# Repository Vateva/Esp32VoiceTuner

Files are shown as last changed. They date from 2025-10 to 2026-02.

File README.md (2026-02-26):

# esp32-s3-voice-tuner
Real-time voice/instrument tuner using ESP32-S3 with dual-core FreeRTOS, YIN pitch detection, and round GC9A01 display.

Main objective is to learn multithreading with true parallel processing across multiple cores and gain deeper experience with embedded systems development.

## Table of Contents
- [Hardware Components](#hardware-components)
- [Pinout Configuration](#pinout-configuration)
- [Wiring and Assembly](#wiring-and-assembly)
- [Key Features](#key-features)
- [Technical Specifications](#technical-specifications)
- [Known Limitations](#known-limitations)
- [Build Environment](#build-environment)
- [Videos](#videos)

## Hardware Components
- ESP32-S3 Super Mini (or ESP32-S3 Zero)
- GC9A01 Round Display (240x240, 1.28")
- INMP441 MEMS Microphone
- TP4056 Charging Module
- 3.7V 3000mAh Li-Ion Battery
- 2x Momentary Push Buttons
- Power Switch

## Pinout Configuration

### GC9A01 Display (SPI)
```cpp
TFT_SCK  = GPIO 1   // SPI clock
TFT_MOSI = GPIO 2   // SPI data out
TFT_CS   = GPIO 5   // chip select
TFT_DC   = GPIO 4   // data/command
TFT_RST  = GPIO 3   // reset
TFT_BLK  = GPIO 6   // backlight (PWM controlled)
```

### INMP441 Microphone (I2S)
```cpp
I2S_SCK = GPIO 13   // bit clock
I2S_WS  = GPIO 12   // word select (LRCK)
I2S_SD  = GPIO 11   // serial data
```

### Control Buttons
```cpp
BUTTON_DOWN   = GPIO 10  // menu navigation (with internal pullup)
BUTTON_SELECT = GPIO 9   // menu entry/parameter cycling (with internal pullup)
```

Buttons are active low (pressed = LOW, released = HIGH)

## Wiring and Assembly

### Breadboard
tunerBreadBoard

### Soldered guts
tunerSoloderedGuts

### Casing
casing

### In casing
inCasing

### Finished
tunerFinished1

**Power:**
- TP4056 handles battery charging via USB
- Power switch controls main power
- Battery provides portable operation

## Key Features

### True Dual-Core Processing
Leverages both ESP32-S3 cores for parallel processing:
- **Core 0 (Audio Task):** continuous I2S audio capture at 48kHz, dB level monitoring, power state management
- **Core 1 (Processing Task):** YIN pitch detection, display rendering, menu system, button handling
- FreeRTOS queues and mutexes ensure thread-safe communication
- Independent task priorities prevent blocking

### YIN Pitch Detection Algorithm
Two-pass implementation with harmonic validation:
- **Coarse Pass:** fast period estimation using 512 samples, quality gating at 0.5 threshold
- **Refined Pass:** focused search window (±40% configurable) around coarse estimate, parabolic interpolation for sub-sample precision
- **Harmonic Scoring:** validates fundamental by checking 2nd, 3rd, and 4th harmonics with weighted correlation
- **Multi-Candidate Ranking:** evaluates up to 8 period candidates using composite scoring (YIN quality 40%, harmonic content 50%, frequency bias 10%)

### Audio Preprocessing
Cascaded 2nd-order Butterworth IIR filters:
- **Highpass Filter:** removes DC offset and low frequency noise (60-120Hz configurable)
- **Lowpass Filter:** removes high frequency noise above vocal harmonics (4000-8000Hz configurable)
- **Audio Gain:** input amplification (1.0x to 10.0x configurable)

### Confidence-Based Smoothing
Multi-factor confidence calculation for adaptive filtering:
- **YIN Quality (35%):** exponential decay based on YIN difference function value
- **Harmonic Content (25%):** strength of detected harmonics in signal
- **Signal Strength (25%):** sigmoid-mapped RMS level
- **Frequency Stability (15%):** variance of recent 5 measurements
- Dynamic EMA alpha (0.25-0.85) scales smoothing based on overall confidence
- Automatic note change detection with immediate acquisition (6% frequency change threshold)

### Power Management
dB-based audio detection with dynamic CPU frequency scaling:
- **Detecting Mode:** 80MHz CPU, skips YIN analysis, monitors dB level only, displays animated sleep screen
- **Analyzing Mode:** 240MHz CPU, full pitch detection pipeline, normal tuner display
- Configurable activation threshold (-10 to -25dB), deactivation threshold (-20 to -40dB), silence timeout (2-10 seconds)
- Retriggerable timer prevents premature sleep during pauses

### Menu System
Comprehensive parameter configuration with flash persistence:
- **Tuning Parameters:** flat/sharp threshold (10-25 cents), smoothing level (1-5), scale selection (10 scales), root note (12 notes)
- **Audio Prefiltering:** highpass/lowpass cutoffs, audio gain
- **Display Settings:** brightness (PWM controlled 10-100%), cents display toggle, note naming (English/Solfège)
- **System Settings:** silence timeout, YIN search window, menu timeout, factory reset
- Two-button navigation (DOWN=navigate, SELECT=enter/cycle)
- Auto-save on exit with validation

### Musical Scales
Supports 10 different scales with configurable root note:
- Chromatic (all 12 notes)
- Major, Natural Minor, Harmonic Minor, Melodic Minor
- Major Pentatonic, Minor Pentatonic
- Blues, Dorian, Mixolydian
- Automatically snaps detected frequency to nearest scale note
- Calculates cents offset from perfect pitch within selected scale

## Technical Specifications

### Performance
- **Sample Rate:** 48kHz mono
- **Buffer Size:** 2048 samples (~43ms audio window)
- **Capture Interval:** 64ms (15.6 fps processing rate)
- **End-to-End Latency:** ~35ms (capture → analysis → display)
- **Frequency Range:** 40-1000Hz (code supports), 90-1000Hz (stable/verified)

## Known Limitations
- **Frequency Range:** while code theoretically supports 40-1000Hz, stable/reliable detection verified in 90-1000Hz range
- **Display Hardware:** code specifically written for GC9A01 240x240 round display, other displays require code modifications
- **Microphone Positioning:** optimal performance at ~15cm distance (varies with volume/gain settings)

## Build Environment
**PlatformIO Configuration:**
- Board: `esp32-s3-devkitc-1`
- Framework: Arduino-ESP32
- Library Dependencies: `lovyan03/LovyanGFX@^1.1.12`

Upload with default PlatformIO settings - no special configuration required.

## Videos

### Test video

https://github.com/user-attachments/assets/ada7eb09-d798-44a8-a253-f5996cc67c34

### Menu navigation and sleep

https://github.com/user-attachments/assets/7b2660a6-9329-4d96-aefc-cad8921d8ced

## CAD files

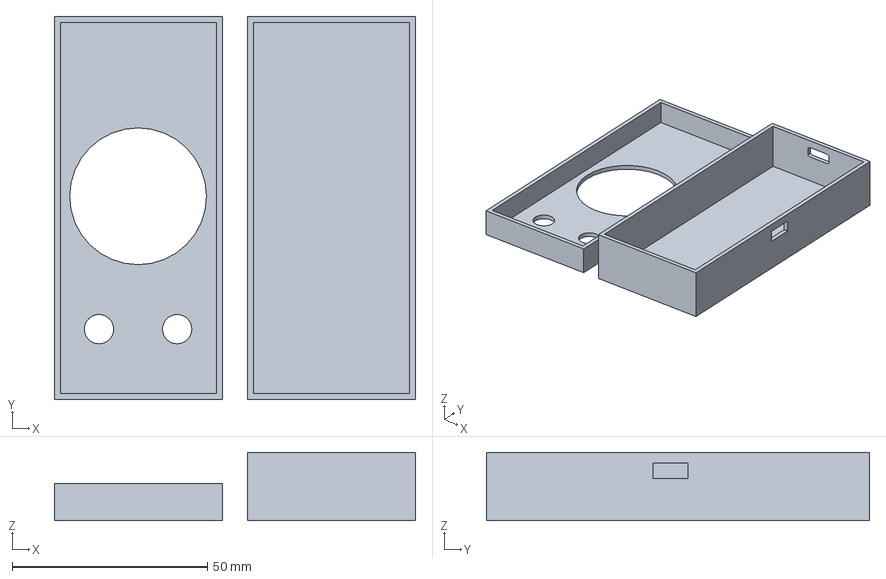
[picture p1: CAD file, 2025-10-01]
casingFiles3DPrint/tunerWithMicHoles.3mf
92.4 x 98.0 x 17.5 mm

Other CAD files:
casingFiles3DPrint/tunerNoMicHoles.stl
casingFiles3DPrint/tuner.blend

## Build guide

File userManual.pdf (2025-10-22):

# Voice Tuner

### User Manual

## Contents

Quick Start | 3
Button Controls | 4
Power Saving | 5
Menu Navigation | 6
Tuning Parameters | 7
Scale Types | 10
Audio Settings | 11
Display Settings | 13
System Settings | 15
Troubleshooting | 17
Tips & Best Results | 19

## Quick Start

Your voice tuner displays a circular interface showing pitch accuracy in real-time.
Circle Colors

Green: Perfect pitch (within threshold) Yellow/Orange: Close but slightly off Red: Significantly sharp or flat
What You See

The device shows the note name (like "C4", "A3") and cents deviation from perfect pitch.

The dynamic circle grows or shrinks to show how far you are from the target note.

Cents: A cent is 1/100th of a semitone. 0 cents = perfect pitch.

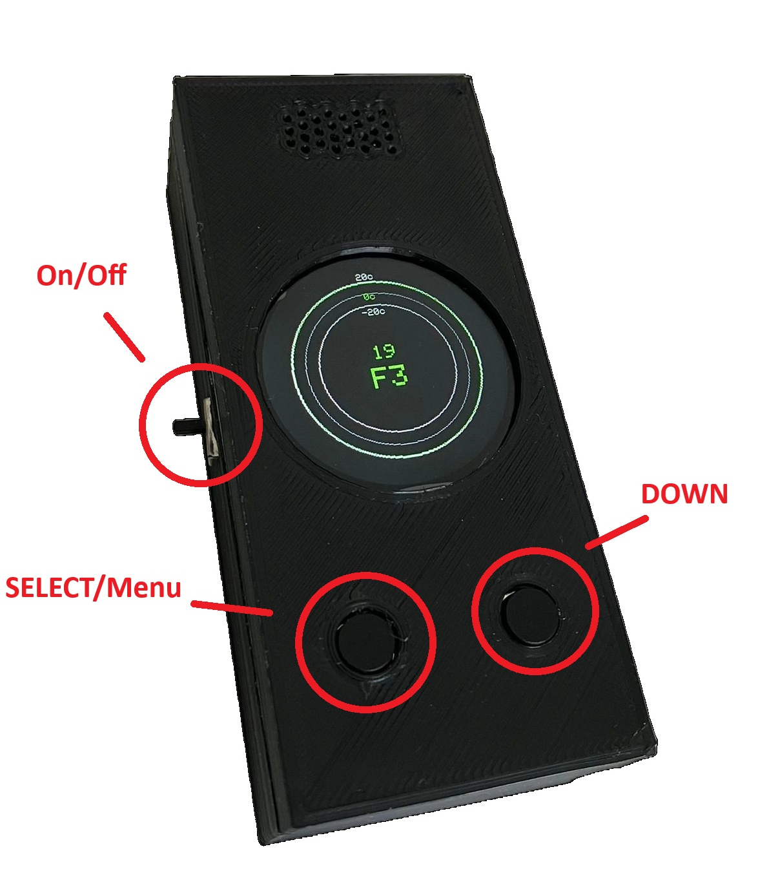
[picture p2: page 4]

## Button Controls

DOWN Button

Navigate down through menu items. The selection loops around to the top when you reach the bottom.
SELECT Button

Multi-function button:

Open the menu from tuner screen Enter submenu
Cycle through parameter values

Quick Access: Press SELECT once from the tuner screen to open the menu.

Navigation Flow

### 1. Press SELECT to open menu 2. Press DOWN to navigate 3. Press SELECT to enter/change 4. Select "Exit" to apply changes

## Power Saving Mode

The tuner automatically enters sleep mode when no sound is detected for several seconds.
Sleep Display

You'll see animated "zzz" characters floating upward with the message "Asleep but listening..."
Auto Wake-Up

The tuner wakes automatically when you start singing or playing. No button press needed!

Battery Saver: This feature significantly extends battery life during practice sessions with pauses.

Adjusting Sleep Time

You can change how long the tuner waits before sleeping in System Settings → Silence Timeout (2-10 seconds).

## Menu Navigation

Action | How To
Open menu | SELECT once
Navigate | DOWN (loops)
Change value | SELECT (cycles)
Go back | Select "Back"
Apply & exit | Select "Exit"

Menu Structure

Main Menu:
Tuning Parameters
Audio Prefiltering
Display
System
Exit

Auto-Exit: The menu closes automatically after 10 seconds of inactivity (adjustable).

## Tuning Parameters

Flat/Sharp Threshold

Range: 10-25 cents
Sets how strict the tuner is about pitch accuracy.
10-15 cents: Strict mode. Shows green only when very accurate.

20-25 cents: Forgiving mode. Shows green with slight variations.

Start with 15c: Increase if too demanding, decrease for stricter feedback.

Smoothing Level

Range: 1-5
Controls how quickly the display responds to pitch changes.
Level 1-2: Very responsive, jumps quickly. Can be jittery on unstable notes.

Level 3: Balanced (recommended).
Level 4-5: Very smooth, slower to respond. Good for holding steady notes.

Modify if: Display too jumpy->Increase smoothing. Feels sluggish->Decrease it.

Root Note

Sets the starting note of your chosen scale (only matters when not using Chromatic).

Tuner will display how far of the closest note in the current scale and root note the detected pitch is.

Example: Want to know how far of the closest G Major note the detected pitch is? Set Scale Type to "Major" and Root Note to "G".

## Scale Types

Restricts the tuner to only show notes in a specific musical scale.
Tuner will display how far of the closest note in the current scale and root note the detected pitch is.
Available Scales

Chromatic
Major
Natural Minor
Harmonic Minor
Melodic Minor
Major Pentatonic
Minor Pentatonic
Blues
Dorian
Mixolydian

In equal temperament, the chromatic scale is divided into twelve equally-spaced semitones

## Audio Prefiltering

Advanced: Most users won't need to change these settings.

Highpass Cutoff

Range: 60-120 Hz
Removes very low frequencies like room rumble and handling noise.

Default: 60 Hz works for most voices.

Modify if: You want to filter out higher(up to 120) Hz sounds.

Lowpass Cutoff

Range: 4000-8000 Hz
Removes very high frequencies like room hiss and breath noise.
Default: 6000 Hz works for most voices and situations.

If you set it too low you can filter out some important harmonics.

Audio Gain

Range: 1.0x - 10.0x
Amplifies microphone input.

Low gain (1-2x): Quiet signal, but less environmental noise pickup.
Moderate gain (3x, default: Good balance. Strong vocals detected, background noise mostly ignored.
High gain (8-10x): Detects very quiet singing BUT also picks up room noise, breathing, handling noise.

High gain can cause false triggers and unstable pitch detection.

Modify if: Tuner shows "Asleep" when singing, increase gain. Too sensitive to noise, decrease it. 12

## Display Settings

Brightness

Range: 10-100%
Controls screen brightness. Show Cents

ON or OFF
Displays numerical cents offset above note name.

ON: Shows precise numerical feedback (e.g., "+3" cents) OFF: Cleaner display with only colored circle feedback. Note Names

Changes how note names are displayed.

English: C, D, E, F, G, A, B
Solfège: Do, Re, Mi, Fa, Sol, La, Si

## System Settings

Silence Timeout

Range: 2-10 seconds
How long to wait before entering sleep mode. Default: 5 seconds

YIN Search Window

Range: 20-40%
Defines the search range for the refined pitch detection pass around the initial estimate.
Default: 40% provides robust detection for most voices.

Modify if: Lower to 20-25% for faster processing with very clear, stable voices. Keep higher (35-40%) for more robust detection with varied singing or less ideal conditions.

Lower this value only if you absolutely need faster processing.

Menu Timeout

Range: 2-10 seconds
How long menu stays open before auto-closing.

Default: 10 seconds

## Troubleshooting

Shows "Asleep" when singing

Solution: Increase Audio Gain or sing louder. Display too jumpy

Solution: Increase Smoothing Level to 4-5. Display too slow

Solution: Decrease Smoothing Level to 1-2. Wrong note detected

Solution: Lower YIN Search Window to 25-30%.

Too strict/forgiving

Solution: Adjust Flat/Sharp Threshold. Lower = stricter, Higher = more forgiving.

Too sensitive to noise

Solution: Lower Audio Gain to 2.0-2.5x.

Does not pick up the sound.

Solution:Increase Audio Gain.

Factory Reset

Menu → System → Factory Reset

Restores all settings to defaults.

## Tips for Best Results

1. Hold device close(20cm) and at a steady distance from your mouth for optimal pickup.
2. Use in a reasonably noise free. Background noise affects detection.
3. Poliphonic sounds will confuse the device.
4. The tuner works best with sustained notes. Quick passages may not register accurately.
5. Battery Life
Lower screen brightness
Use shorter silence timeout
Use shorter Sleep mode timeout

Voice Tuner

For support and updates,
refer to product documentation

User manual

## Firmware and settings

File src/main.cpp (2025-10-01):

#include "audioprocessing.h"
#include "config.h"
#include "display.h"
#include "menu.h"
#include "tasks.h"
#include "utilities.h"
#include <Arduino.h>

// system initialization
void setup() {
#if ENABLE_SERIAL_MONITOR_PRINT
  Serial.begin(SERIAL_BAUD_RATE);
  delay(2000);

  // startup banner and system info
  Serial.println("=== ESP32-S3 Multi-Core Voice Tuner with GC9A01 Display ===");
  Serial.printf("CPU Frequency: %d MHz\n", getCpuFrequencyMhz());
  Serial.printf("Timing Debug: %s\n",
                ENABLE_TIMING_DEBUG ? "ENABLED" : "DISABLED");
  Serial.println(
      "Algorithm: Multi-Candidate YIN (Enhanced Harmonic Detection)");
  Serial.printf("Audio Prefiltering: HP=%.0f Hz, LP=%.0f Hz\n",
                HIGHPASS_CUTOFF_HZ, LOWPASS_CUTOFF_HZ);

  // power management configuration
  Serial.println("=== POWER MANAGEMENT FEATURES ===");
  Serial.printf("dB Detection: Activation=%.1fdB, Deactivation=%.1fdB\n",
                DB_ACTIVATION_THRESHOLD, DB_DEACTIVATION_THRESHOLD);
  Serial.printf("Silence Timeout: %d seconds\n", SILENCE_TIMEOUT_MS / 1000);
  Serial.printf("CPU Frequencies: Detecting=%dMHz, Analyzing=%dMHz\n",
                DETECTING_CPU_FREQ, ANALYZING_CPU_FREQ);
  Serial.printf("Initial Power State: %s\n",
                (currentPowerState == DETECTING) ? "DETECTING" : "ANALYZING");
#endif

  // display hardware setup
  initDisplay();
    
  startupAnimation();

  // menu system early initialization (gpio setup)
  safePrintf("initializing menu system...\n");
  // note: full menu initialization happens in processing task
  // this just sets up gpio pins early
  pinMode(BUTTON_DOWN_PIN, INPUT_PULLUP);
  pinMode(BUTTON_SELECT_PIN, INPUT_PULLUP);

  
  // load saved parameters from flash
  safePrintf("loading saved parameters...\n");
  loadParametersFromFlash();



  // audio subsystem initialization (includes filter setup)
  if (!initI2S()) {
    Serial.println("FATAL: I2S initialization failed");
    tft.setTextColor(TFT_RED);
    tft.drawCenterString("I2S FAILED!", 120, 170);
    return;
  }


  // freertos synchronization primitives
  serialMutex = xSemaphoreCreateMutex();
  statsMutex = xSemaphoreCreateMutex();
  displayMutex = xSemaphoreCreateMutex();

  if (!serialMutex || !statsMutex || !displayMutex) {
    Serial.println("FATAL: Failed to create mutexes");
    tft.setTextColor(TFT_RED);
    tft.drawCenterString("MUTEX FAILED!", 120, 190);
    return;
  }

  Serial.println("Mutexes created successfully");

  // inter-task communication queue
  audioQueue = xQueueCreate(AUDIO_QUEUE_LENGTH, sizeof(AudioBuffer *));

  if (!audioQueue) {
    Serial.println("FATAL: Failed to create audio queue");
    tft.setTextColor(TFT_RED);
    tft.drawCenterString("QUEUE FAILED!", 120, 190);
    return;
  }

  Serial.println("Audio queue created successfully");

  // initialize power management state
  currentPowerState = ANALYZING;
  silenceTimer = 0;
  lastSoundTime = millis();

  // set initial cpu frequency for analyzing mode
  setCpuFrequency(ANALYZING_CPU_FREQ);

  // dual-core task creation with affinity
  BaseType_t result1 = xTaskCreatePinnedToCore(
      audioTask, "AudioTask", AUDIO_TASK_STACK_SIZE, NULL, AUDIO_TASK_PRIORITY,
      &audioTaskHandle, AUDIO_TASK_CORE);

  BaseType_t result2 = xTaskCreatePinnedToCore(
      processingAndDisplayTask, "ProcessingTask", PROCESSING_TASK_STACK_SIZE,
      NULL, PROCESSING_TASK_PRIORITY, &processingTaskHandle,
      PROCESSING_TASK_CORE);

  if (result1 != pdPASS || result2 != pdPASS) {
    Serial.println("FATAL: Failed to create tasks");
    tft.setTextColor(TFT_RED);
    tft.drawCenterString("TASK FAILED!", 120, 210);
    return;
  }

  Serial.println("All tasks created successfully");
  Serial.println("System starting with dB Detection Power Management...\n");
  // show power management status
  safePrintf("=== POWER STATE INITIALIZED ===\n");
  safePrintf("Mode: %s\n",
                (currentPowerState == DETECTING) ? "DETECTING" : "ANALYZING");
  safePrintf("CPU: %d MHz\n", getCpuFrequencyMhz());
  safePrintf("====================================\n\n");

  //draw interface when everything is initialized
  drawTunerInterface();

}

// main loop with watchdog prevention
void loop() {
  // yield to freertos scheduler
  vTaskDelay(pdMS_TO_TICKS(1000));
}

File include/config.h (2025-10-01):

#ifndef CONFIG_H
#define CONFIG_H

#include <Arduino.h>
#include <driver/i2s.h>

// =================================================================
// DEBUGGING
// =================================================================
#define ENABLE_TIMING_DEBUG 0
#define ENABLE_CONFIDENCE_DEBUG 0
#define ENABLE_SERIAL_MONITOR_PRINT 0
#define SERIAL_BAUD_RATE 115200

// =================================================================
// HARDWARE PINS
// =================================================================
// gc9a01 round display
#define TFT_SCK     1   // spi clock
#define TFT_MOSI    2   // spi data out
#define TFT_CS      5   // chip select
#define TFT_DC      4   // data/command
#define TFT_RST     3   // reset
#define TFT_BLK     6   // backlight

// inmp441 microphone
#define I2S_SCK_PIN       13   // bit clock
#define I2S_WS_PIN        12   // word select
#define I2S_SD_PIN        11   // serial data

// =================================================================
// I2S & AUDIO PROCESSING
// =================================================================
#define I2S_PORT          I2S_NUM_0
#define I2S_SAMPLE_RATE   48000
#define I2S_SAMPLE_BITS   I2S_BITS_PER_SAMPLE_32BIT
#define I2S_CHANNELS      I2S_CHANNEL_MONO
#define I2S_DMA_BUF_COUNT 32
#define I2S_DMA_BUF_LEN   64
#define AUDIO_BUFFER_SAMPLES 2048

// audio prefiltering
#define HIGHPASS_CUTOFF_HZ    60.0f    // default frecuency to remove dc offset and low frequency noise, configurable runtime parameter
#define LOWPASS_CUTOFF_HZ   6000.0f    // default frecuency to remove high frequency noise above harmonics, configurable runtime parameter
#define AUDIO_GAIN_FACTOR     3.0f     // default audio input gain multiplier, configurable runtime parameter

// audio processing constants
#define INT24_TO_FLOAT_DIVISOR        8388608.0f  // 2^23 for 24-bit signed to float conversion
#define I2S_READ_TIMEOUT_MS           100         // i2s read operation timeout
#define AUDIO_SILENCE_FLOOR_DB        -80.0f      // minimum db level (silence floor)

// =================================================================
// YIN PITCH DETECTION ALGORITHM
// =================================================================
#define YIN_MIN_PERIOD 32
#define YIN_MAX_PERIOD 600

// Coarse Pass
#define YIN_COARSE_THRESHOLD 0.25f
#define YIN_COARSE_SAMPLES 512
#define YIN_COARSE_MIN_VALID_SAMPLES 64
#define YIN_COARSE_QUALITY_GATE 0.5f

// Refined Pass
#define YIN_THRESHOLD         0.15f    // detection confidence
#define YIN_SEARCH_WINDOW     0.40f    //default  ±40% search range, configurable runtime parameter
#define YIN_MAX_CANDIDATES    8        // max candidates for refined analysis

// Harmonic Scoring
#define YIN_HARMONICS_TO_CHECK {2, 3, 4}
#define YIN_HARMONIC_WEIGHTS {0.8f, 0.6f, 0.4f}
#define YIN_MIN_HARMONIC_VALID_SAMPLES 32
#define YIN_MIN_HARMONIC_PERIOD 16
#define YIN_HARMONIC_CORRELATION_THRESHOLD 0.1f
#define YIN_HARMONIC_BONUS 1.5f

// Candidate Selection Weights
#define YIN_SCORE_WEIGHT 0.4f
#define HARMONIC_SCORE_WEIGHT 0.5f
#define FREQUENCY_BIAS_WEIGHT 0.1f

// Vocal Range Frequency Bias
#define VOCAL_RANGE_MIN 80.0f
#define VOCAL_RANGE_MAX 600.0f
#define VOCAL_RANGE_HIGH_MAX 1000.0f
#define VOCAL_RANGE_LOW_MIN 40.0f
#define VOCAL_PENALTY_HIGH 0.3f
#define VOCAL_PENALTY_LOW 0.2f
#define VOCAL_PENALTY_EXTREME 0.5f

// =================================================================
// SMOOTHING & CONFIDENCE
// =================================================================
#define MIN_CONFIDENCE_THRESHOLD  0.15f  // minimum confidence for display update
#define MIN_RMS_THRESHOLD        0.008f  // minimum signal level
#define EMA_ALPHA_MIN            0.25f   // more smoothing for low confidence
#define EMA_ALPHA_MAX            0.85f   // less smoothing for high confidence
#define FREQUENCY_STABILITY_WINDOW 5     // samples for stability calculation
#define A4_REFERENCE_PITCH       440.0f  // a4 = 440 hz

// confidence calculation constants
#define CONFIDENCE_YIN_WEIGHT           0.35f    // weight for yin quality in overall confidence
#define CONFIDENCE_HARMONIC_WEIGHT      0.25f    // weight for harmonic content in overall confidence
#define CONFIDENCE_SIGNAL_WEIGHT        0.25f    // weight for signal strength in overall confidence
#define CONFIDENCE_STABILITY_WEIGHT     0.15f    // weight for frequency stability in overall confidence
#define YIN_CONFIDENCE_MAX_VALUE        0.5f     // Maximum yin value for confidence calculation
#define YIN_CONFIDENCE_DECAY_FACTOR     3.0f     // Exponential decay factor for yin confidence
#define SIGNAL_CONFIDENCE_GOOD_LEVEL    0.1f     // Signal level considered "good" for confidence
#define SIGNAL_CONFIDENCE_SIGMOID_FACTOR 8.0f    // Sigmoid steepness for signal confidence transition
#define STABILITY_MIN_RELATIVE_DEV      0.001f   // Minimum relative deviation for perfect stability
#define STABILITY_MAX_RELATIVE_DEV      0.02f    // Maximum relative deviation for zero stability
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

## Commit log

2025-08-05 first attempt at pitch detection(autocorrelation)
2025-08-05 two pass pitch detection(autocorrelation + guided YIN)
2025-08-05 two pass pitch detection V2(HPS + YIN)
2025-08-06 changed first pass HSP to a first coarse YIN, now device can be used with less harmonic rich sounds, upped sample rate to 48kHz and buffer size to 2048 for tighter cent spread
    [main.cpp]
2025-08-07 broke up monolithic file into manageable pieces, started working a bit on the display
    [config.h, display.cpp, main.cpp]
2025-10-01 added 3d printing files and user manual
    [tuner.blend, tunerNoMicHoles.stl, tunerWithMicHoles.3mf]
